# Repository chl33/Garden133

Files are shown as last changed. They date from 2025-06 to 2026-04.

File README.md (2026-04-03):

# Garden133 (v1.0.0)

Garden133 is a solar and battery-powered device for monitoring garden soil moisture levels.
It reads the moisture level of soil using a capacitive moisture sensor and transmits data via LoRa.

Please see the [Introducing Garden133](https://selectiveappeal.org/posts/garden133/) blog
post for a project overview.

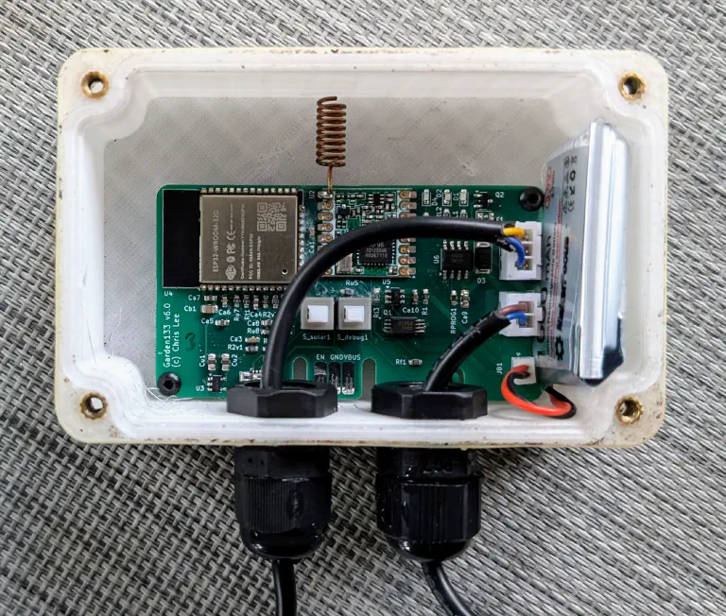
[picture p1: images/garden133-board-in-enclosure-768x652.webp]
Garden133 in enclosure


## Features
- **Modern Web Interface:** A responsive Svelte-based UI for real-time status monitoring and calibration (accessible in Debug Mode).
- **Soil Moisture Sensing:** Capacitive sensor measurement with high-precision calibration.
- **Dedicated Calibration Page:** View live ADC counts to precisely tune dry/wet thresholds.
- **Device Environmental Monitoring:** SHTC3 sensor for air temperature and humidity inside the device enclosure.
- **Power Management:** Solar charging and battery voltage monitoring.
- **LoRa Communication:** Connects to a base station ([LoRa133](https://github.com/chl33/LoRa133)) to integrate with Home Assistant.
- **OTA Updates:** Support for wireless firmware updates.

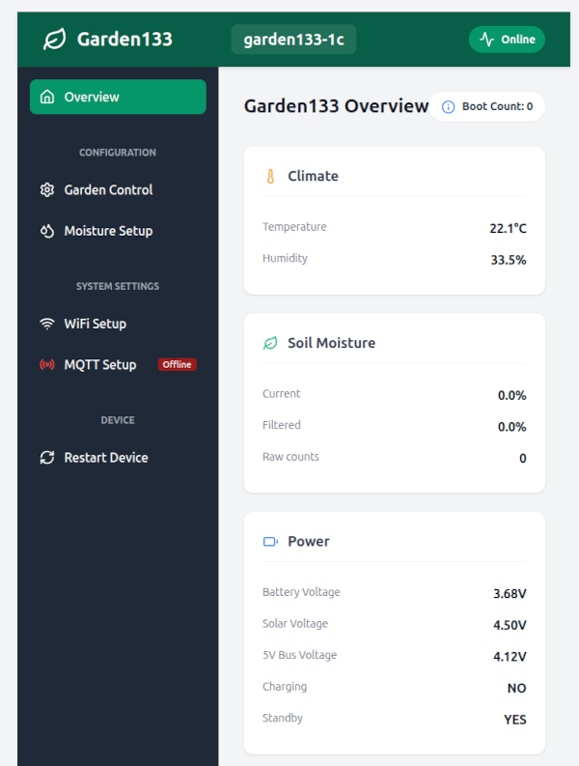
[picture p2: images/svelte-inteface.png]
Svelte Web interface


## Hardware
This project includes the custom hardware design and 3D printable parts.

- **PCB Design:** KiCAD files are available in [`KiCAD/Garden133/`](KiCAD/Garden133/).
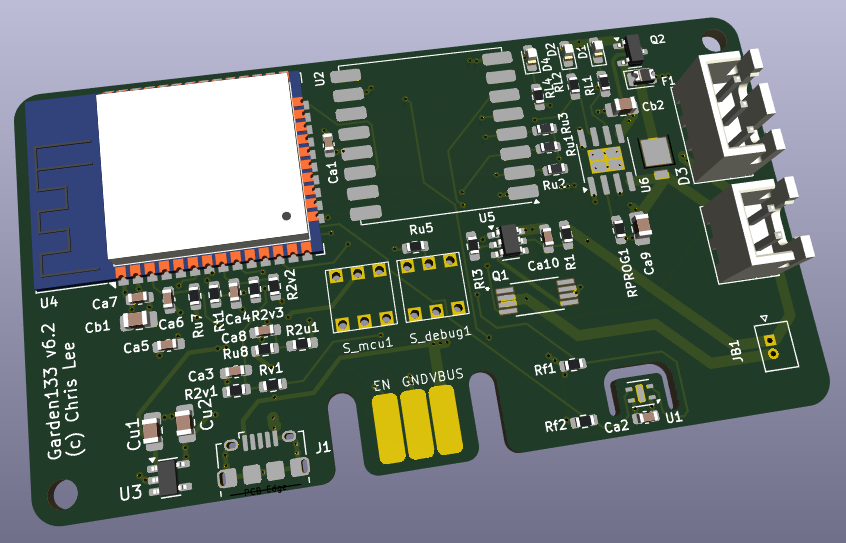
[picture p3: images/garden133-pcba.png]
Garden133 PCBA
  
- **Enclosure:** OpenSCAD files for the waterproof enclosure and mounts are in [`OpenSCAD/`](OpenSCAD/).

## Firmware Dependencies
This firmware uses the [PlatformIO](https://platformio.org/) build system and depends on the following libraries:
- [og3](https://github.com/chl33/og3): Base C++ library for ESP32/Arduino.
- [og3x-lora](https://github.com/chl33/og3x-lora): LoRa module support.
- [og3x-satellite](https://github.com/chl33/og3x-satellite): Satellite architecture support.

## Getting Started

### Prerequisites
- [PlatformIO Core](https://docs.platformio.org/en/latest/core/index.html) or VSCode with PlatformIO extension.
- An ESP32-based Garden133 board.

### Configuration
The project uses INI files for local configuration (secrets, paths, etc.) which are excluded from git.

1. **Setup Secrets:**
   Copy the example secrets file to create your local configuration:
   ```bash
   cp secrets.ini.example secrets.ini
   ```
   Edit `secrets.ini` to set your environment preferences:
   - `udpLogTarget`: IP address for UDP logging.
   - `otaPassword`: Password for Over-The-Air updates.
   - `uploadProtocol`: `esptool` (USB) or `espota` (WiFi).
   - `uploadPort`: Serial port (e.g., `/dev/ttyUSB0`) or IP address.

2. **USB vs WiFi:**
   You can also use `secrets-usb.ini.example` as a template for USB-connected development:
   ```bash
   cp secrets-usb.ini.example secrets.ini
   ```

### Building & Flashing

1. **Build the firmware:**
   ```bash
   pio run
   ```

2. **Upload the firmware:**
   ```bash
   pio run --target upload
   ```

3. **Upload Filesystem (LittleFS):**
   This uploads the `data/` directory containing web resources.
   ```bash
   pio run --target uploadfs
   ```

## License
This project is licensed under the MIT License. See `LICENSE` for details.

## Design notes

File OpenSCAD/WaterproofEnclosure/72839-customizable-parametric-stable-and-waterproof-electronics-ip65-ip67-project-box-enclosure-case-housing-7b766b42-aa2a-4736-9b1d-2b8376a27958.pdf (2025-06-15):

## Customizable parametric stable

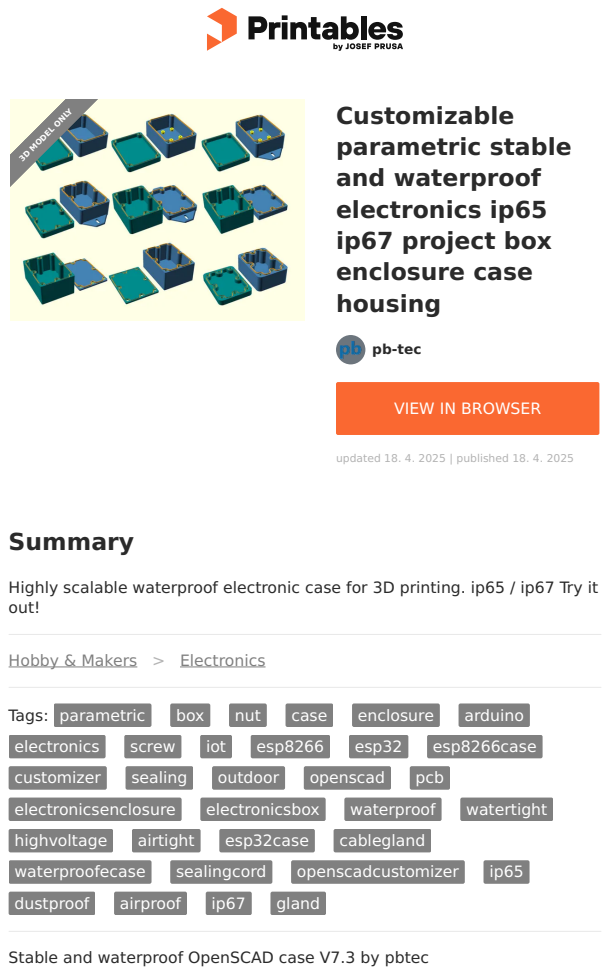
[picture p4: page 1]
Summary; Tags:; parametric; box; nut; case; enclosure; arduino; electronics; screw; iot; esp8266; esp32; esp8266case; customizer; sealing; outdoor; openscad; pcb; electronicsenclosure; electronicsbox; waterproof; watertight; highvoltage; airtight; esp32case; cablegland; waterproofecase; sealingcord; openscadcustomizer; dustproof; airproof; gland; pb-tec; and waterproof electronics ip65 ip67 project box enclosure case housing; updated 18. 4. 2025 | published 18. 4. 2025; 3D MODEL ONLY

VIEW IN BROWSER (https://printables.com/model/72839-customizable-parametric-stable-and-waterproof-elec)

Highly scalable waterproof electronic case for 3D printing. ip65 / ip67 Try it
out!

Hobby & Makers (https://printables.com/model?categoryId=48) > Electronics (https://printables.com/model?categoryId=52)

Stable and waterproof OpenSCAD case V7.3 by pbtec

Highly scalable electronic case for 3D printing. Try it out!
Optimized for Openscad Customizer. Activate it under view/customizer and play around ;-)
Openscad is free opensource software. You can download it here: https://openscad.org/

Fixed version 7.3
It seems that special characters in the code have again led to the code not working properly for some. I apologize for this. I have now created a new version 7.3 where this is fixed. I would be very interested to know if everything works as expected for you now. Thanks for your feedback in the comments

Enhancements in Version 7.2:

Hot melt copper nut support
Screw hole options: Can be configured to pass through the entire case, with the option to position the nut at the bottom of the case Flexible mounting options: 1 to 3 holes on all sides for cable glands or switches
Improved PCB support: Now compatible with up to 3 different PCBs holders instead of just one
Base bottom mounting holes added (not recommended if the housing should be highly waterproof)
Gasket can now be printed (TPU).
Expanded screw support: In addition to countersunk screws, round, flat, and hex head screws are now supported

I would love to hear whether you like the new version!

No support needed to print

You don't know Openscad? No problem. Export the stl file from Openscad (F6 then F7). Then Import the stl file into your best known 3d program to make holes for example.
You can also make the holes afterwards with the drilling machine.

Additional Screws (M2,M2.5,M3,M4 or M5), the matching nuts (hex or square) needed.
If you want to protect your electronics from humidity also “silicone sealing cord” is needed. Available at AliExpress or ebay.

For waterproof cases you can use silicone sealing cord with diameters from 1 to 3mm
To use also without sealing cord. The groove and ridge gives the housing a high stability and tightness.
Use of regular nuts or square nuts
Define outer vertical radius of corners

•
•

•

•

•

•
•

Echo output in console shows inner and outer size and more
Echo output shows the needed length of the screws
Use screws from m2 up to m5
Default are 4 screws at each corner. For large cases add addtional ones in the middle of both x and y sides if needed
Use several predefined wall mount holder, some with multiple mounting holes (up to 3)

Important!
If you use standard or square nuts, you need to pause the printer a certain level to insert the nuts
If you need a stable and waterproof case please print with 100% infill
I'm aware that sometimes, when using too big or too small parameters, there are some rendering issues. To prevent such issues change only one parameter at once and check the result.

I never tested the water proofness of this case. For more information see https://blog.prusaprinters.org/watertight-3d-printing-part-2_53638/

pbtec / pb-tec.ch
https://www.instagram.com/pbtecch/

For Projects with ESP32, ESP8266, Arduino, Raspberry, Sonoff, Shelly, IoBroker, IoT. In- and outdoor :-)

Let me see your prints, and remakes and pls don't forget to like this print

use https://paypal.me/pbtec if you want to spend me a coold beer. Thanks in advance :-)

If you want to support my project, please use the links below to start your shopping. No additional charges for you, but I get a commission of your purchases

Brass hot melting insert nuts (starter) sets: https://s.click.aliexpress.com/e/_DezuAlHhttps://s.click.aliexpress.com/e/_DeWsPMp

Or individual sizes:
https://s.click.aliexpress.com/e/_DkaQObjhttps://s.click.aliexpress.com/e/_DCrO22p

I also recommend using special hot iron to insert the nuts in the right angle:
https://s.click.aliexpress.com/e/_DcHd8Ep

round silicone sealing cord foam white
Aliexpress: https://s.click.aliexpress.com/e/_AdVXC6

## Model files

Ebay: https://www.ebay.com/itm/184394411044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 (https://www.ebay.com/itm/184394411044?siteid=0&campid=5338823684&customid=&toolid=10001)

round silicone sealing cord foam black
Aliexpress: https://s.click.aliexpress.com/e/_A32aUQ
Ebay: https://www.ebay.com/itm/353309685702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 (https://www.ebay.com/itm/353309685702?siteid=0&campid=5338823684&customid=&toolid=10001)

round silicone sealing solid cord white
Aliexpress: https://s.click.aliexpress.com/e/_A07nM2
Ebay: https://www.ebay.com/itm/133527877200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 (https://www.ebay.com/itm/133527877200?siteid=0&campid=5338823684&customid=&toolid=10001)

Some tags to better find this project:
Electrical Junction, Distribution box, Connection box, Cable Branch box,
Electronic, Housing, ip67, DIY, Project Box, Instrument Case, Wiring socket
box, Sealed, Cable gland, Shell, weatherproof, outdoor, airtight, watertight, dustproof, electronics, pcb, airproof, enclosure, parametric

sample2-ultimatewaterproofcase_v6.stl

sample1-ultimatewaterproofcase_v6.stl

ultimatewaterproofcase_v61.scad

ultimatewaterproofcase_v73.scad

## License

This work is licensed under a
Creative Commons (4.0 International License)

Attribution—Noncommercial—Share Alike (http://creativecommons.org/licenses/by-nc-sa/4.0/)

✖ | Sharing without ATTRIBUTION
✔ | Remix Culture allowed
✖ | Commercial Use
✖ | Free Cultural Works
✖ | Meets Open Definition

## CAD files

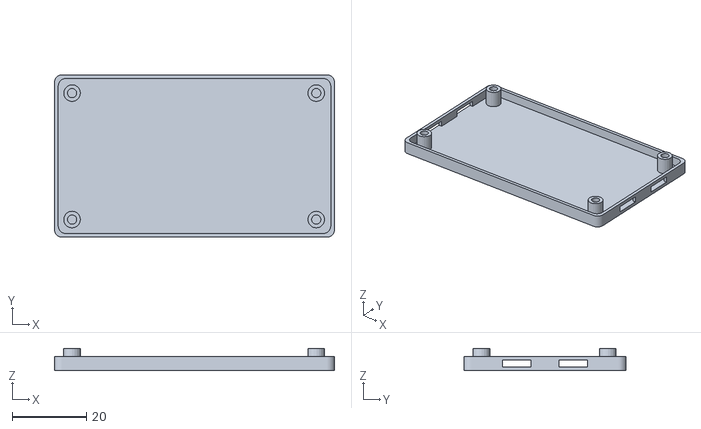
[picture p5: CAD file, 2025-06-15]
OpenSCAD/Garden133/box_bottom.stl
75.5 x 43.8 x 6.00

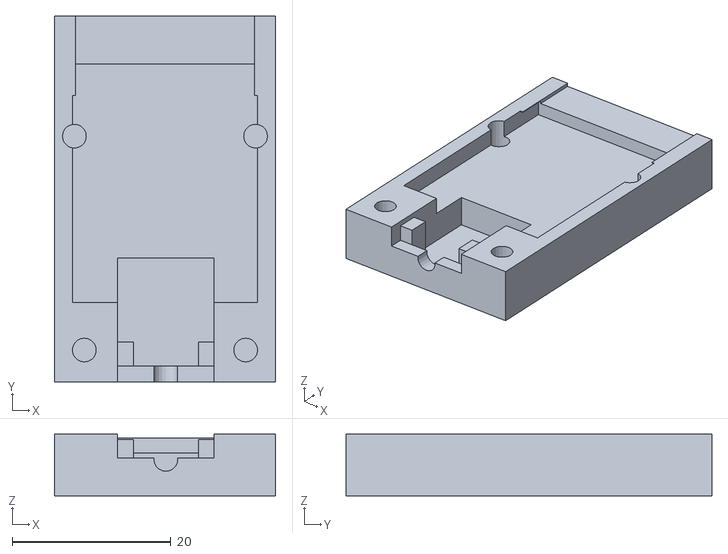
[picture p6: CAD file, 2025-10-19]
OpenSCAD/SoilMoistureCap/box_top.stl
27.8 x 46.0 x 7.78

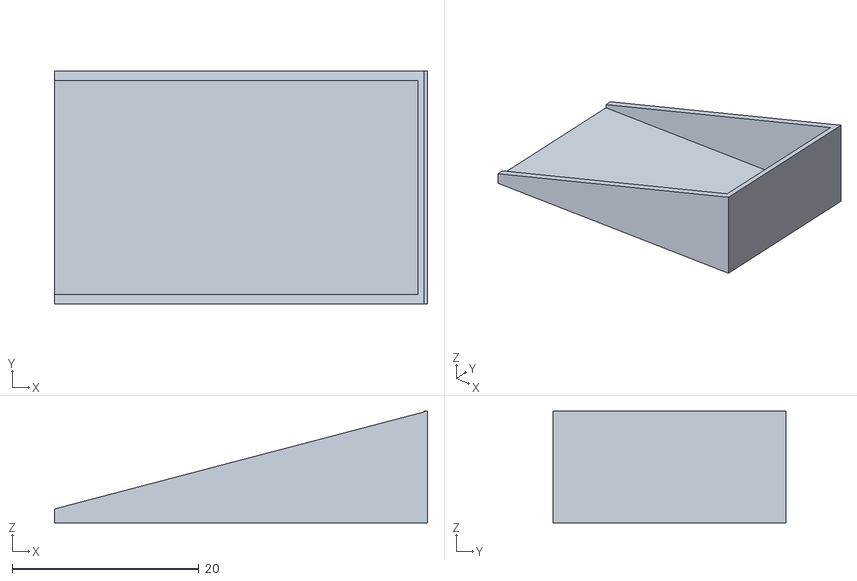
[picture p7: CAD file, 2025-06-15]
OpenSCAD/SoilPot/soilpot.stl
40.0 x 25.0 x 12.0

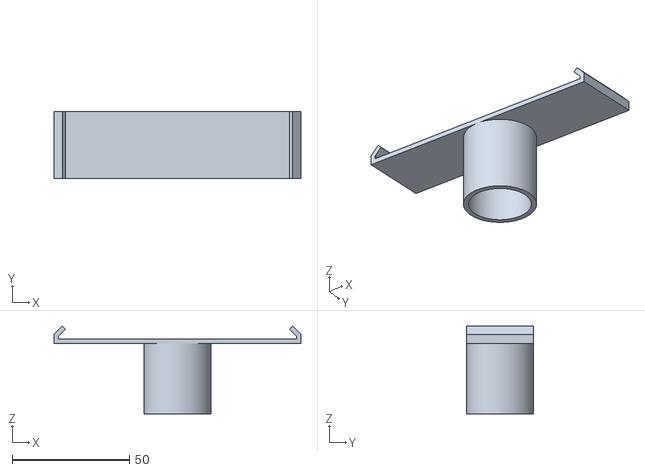
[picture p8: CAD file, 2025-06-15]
OpenSCAD/SolarPanelMount/solar_panel_mount_smaller.stl
105.5 x 28.5 x 37.5

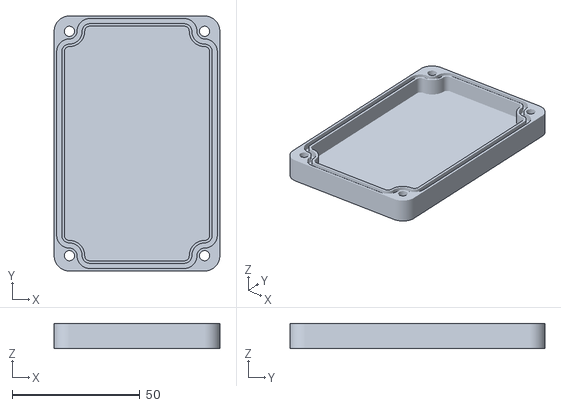
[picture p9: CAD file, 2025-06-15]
OpenSCAD/WaterproofEnclosure/garden133_case_top.stl
65.0 x 100.0 x 10.00

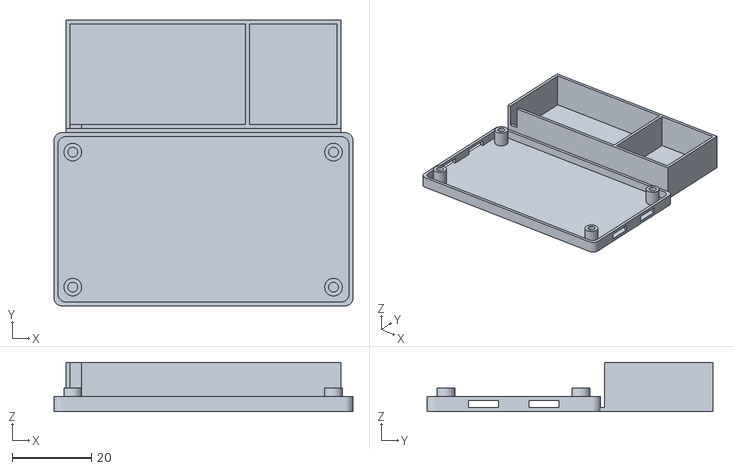
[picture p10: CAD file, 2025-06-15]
OpenSCAD/Garden133/tray.stl
75.5 x 72.2 x 12.4

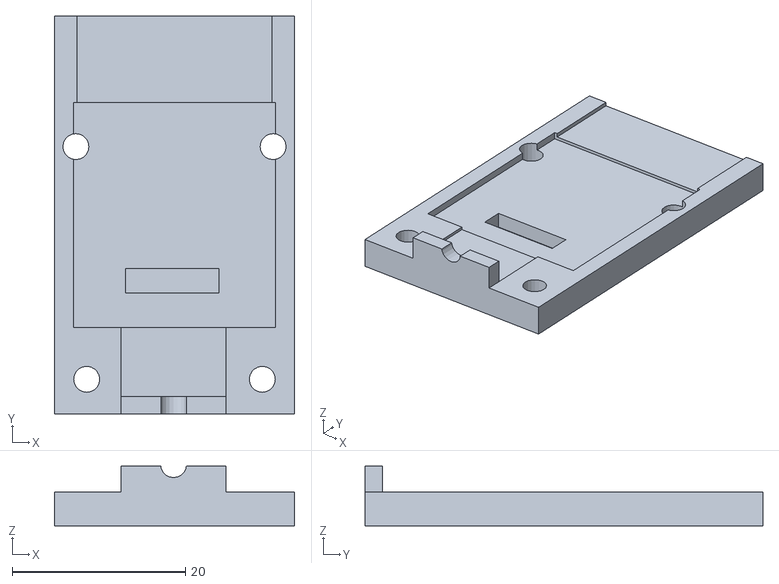
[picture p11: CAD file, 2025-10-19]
OpenSCAD/SoilMoistureCap/box_bottom.stl
27.8 x 46.0 x 6.90

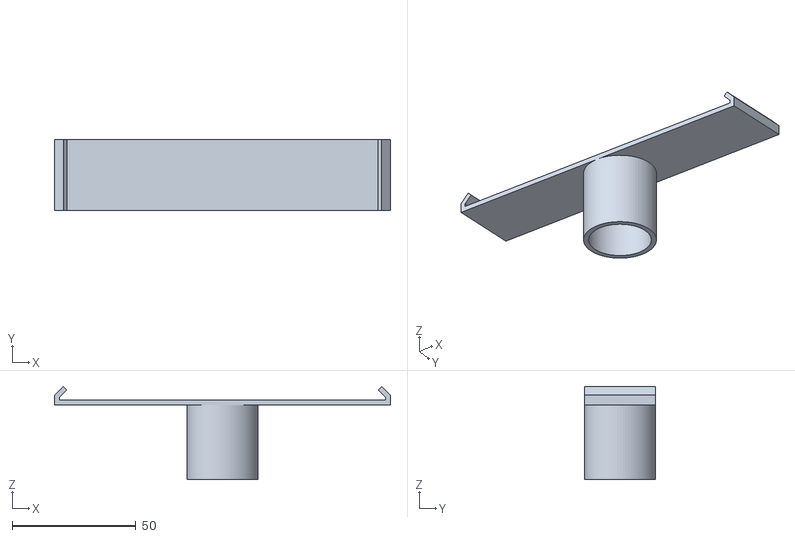
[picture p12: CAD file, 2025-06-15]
OpenSCAD/SolarPanelMount/solar_panel_mount.stl
135.5 x 28.5 x 37.5

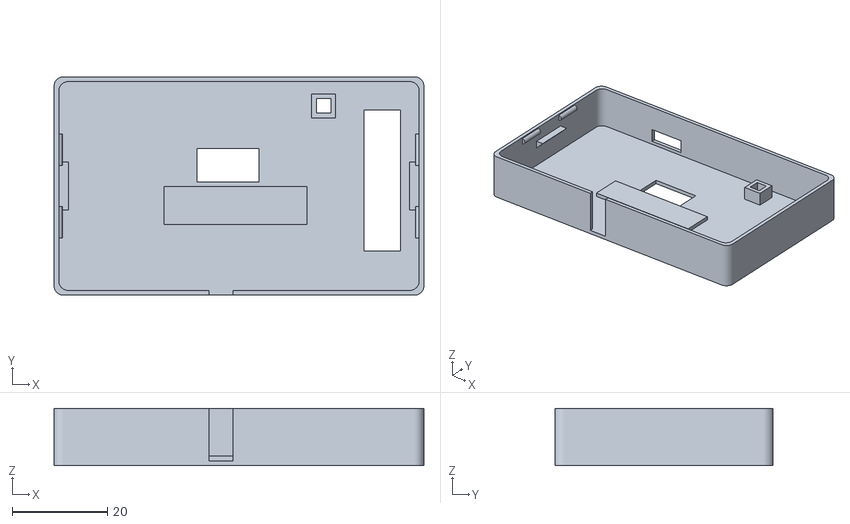
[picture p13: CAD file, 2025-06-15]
OpenSCAD/Garden133/box_top.stl
77.5 x 45.8 x 12.0

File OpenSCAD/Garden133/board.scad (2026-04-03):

// Copyright (c) 2026 Chris Lee and contributors.
// Licensed under the MIT license. See LICENSE file in the project root for details.

include <ProjectBox/project_box.scad>

board_thickness = 1.6;
pad_space = 2.54;
board_dims = [28*pad_space, 15.5*pad_space, board_thickness];

module Garden133_board() {
  u = pad_space;

  // Board imported from KiCad (VRML) -> Blender
  translate([board_dims[0]/2, board_dims[1]/2, board_dims[2]/2]) color("white")
    import(file="Garden133.stl", convexity=3);

}

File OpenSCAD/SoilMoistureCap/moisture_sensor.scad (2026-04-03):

// Copyright (c) 2026 Chris Lee and contributors.
// Licensed under the MIT license. See LICENSE file in the project root for details.

include <MCAD/units.scad>
include <ProjectBox/headers.scad>

moisture_sensor_dims = [22.5, 92, 1];

pin_offset = [6, 4, 0];
pin_size = [10, 2, 2];

cut_out_y1 = 18;
cut_out_dy1 = 1;
cut_out_dy2 = 3;
cut_out_dy = 2 * cut_out_dy1 + cut_out_dy2;
cut_out_dx = 1.75;

moisture_sensor_conn_dims = connector_nx1_dims(3);
moisture_sensor_conn_offset = 
  -header_offset
  + [moisture_sensor_dims[0] / 2,
     moisture_sensor_dims[2] - 1,
     moisture_sensor_dims[2] + moisture_sensor_conn_dims[1] / 2];


module moisture_sensor(space=false) {
  dims = moisture_sensor_dims + Z * (space ? 0.5 : 0);

  offset_val = space ? 0.5 : 0;

  msdx = moisture_sensor_dims[0];
  points = [[0, 0],      // fl
	    [0, cut_out_y1],     // l cut-out fl
	    [cut_out_dx, cut_out_y1 + cut_out_dy1],   // l cut-out fr
	    [cut_out_dx, cut_out_y1 + cut_out_dy1 + cut_out_dy2],   // l cut-out hr
	    [0, cut_out_y1 + cut_out_dy],     // l cut-out hl
	    [0, 28],     // l mid
	    [0, 85],     // hl
	    [msdx/2, moisture_sensor_dims[1]],    // point
	    [msdx, 85],    // hr
	    [msdx, 28],    // r mid
	    [msdx, cut_out_y1 + 2*cut_out_dy1 + cut_out_dy2],    // r cut-out hr
	    [msdx-cut_out_dx, cut_out_y1 + cut_out_dy1 + cut_out_dy2],  // r cut-out hl
	    [msdx-cut_out_dx, cut_out_dy],  // r cut-out fl
	    [msdx, cut_out_y1],    // r cut-out rr
	    [msdx, 0]];    // fr

  translate([1, 1, -1]*offset_val) {
    color("green") {
      linear_extrude(dims[2]+2*offset_val) {
	offset(offset_val)
	  polygon(points = points, paths = [[0, 1, 2, 3, 4, 5, 6, 7, 8, 9, 10, 11, 12, 13, 14]]);
      }
      linear_extrude(2*dims[2]+2*offset_val) {
	offset(offset_val)
	  polygon(points = points, paths = [[0, 1, 2, 3, 4, 5, 9, 10, 11, 12, 13, 14]]);
      }

      component_z = 1.5;
      translate([1, 3, dims[2]-epsilon]) cube([20, 15, component_z]);
      translate([2, 18-epsilon, dims[2]-epsilon]) cube([18, 5, component_z]);
    }
    conn_dims = moisture_sensor_conn_dims;
    if (space) {
      // Reserve simple space for connector when using difference to make space for sensor.
      gap = 0.3;
      space_dims = gap*[2,1,2] + conn_dims;
      color("white") {
	translate([(dims[0]-space_dims[0])/2, -6, dims[2]-0.6-1.4])
	  cube([space_dims[0], space_dims[2]+4.5, space_dims[1]+4]);
      }
    } else {
      translate(moisture_sensor_conn_offset) {
	rotate(180, Y) rotate(90, X) connector_nx1(3, pin_extend=false);
      }
    }
    // Location of pins on the back
    color("white")
      translate([pin_offset[0], pin_offset[1], pin_offset[2] - pin_size[2] + epsilon])
      cube(pin_size);
  }
}

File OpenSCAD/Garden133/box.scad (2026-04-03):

// Copyright (c) 2026 Chris Lee and contributors.
// Licensed under the MIT license. See LICENSE file in the project root for details.

include <ProjectBox/mounts.scad>
include <ProjectBox/project_box.scad>
include <ProjectBox/shtc3_window.scad>
include <board.scad>

ones = [1, 1, 1];

wall_thickness = 1;
gap = 0.2;
corner_radius = 2;
mount_offset = pad_space;

space_above_board = 3;
space_below_board = 5;
inner_dims = (board_dims
	      + Z*(space_above_board+space_below_board)
	      + 2*gap*ones);
outer_dims = (inner_dims
	      + 2*ones*wall_thickness
	      + [2, 2, 0] * corner_radius);

shtc3_loc = [51.8, 1.4];

buttons_loc = [30, 15];
buttons_size = [13, 7];

conn_loc = [65, 7];
conn_size  = [7.6, 29.5];

top_cutouts = [[buttons_loc, buttons_size], [conn_loc, conn_size]];

usb_cutout = [[17.75, wall_thickness+space_below_board+board_thickness-1], [9.5, 3.5]];
ym_cutouts = [usb_cutout];

// Location for "USB DBG" text to carve above buttons
text_loc = [25, 25];

antenna_cutout = [[40, -1], [5, wall_thickness+space_below_board+board_thickness+4.4]];
// antenna_cutout = [[5, wall_thickness+space_below_board+board_thickness+1], [10, 4]];
yp_cutouts = [antenna_cutout];

module in_Garden133_board_frame(board_height=false) {
  zoffset = wall_thickness + (board_height ? space_below_board : 0);
  in_board_frame(outer_dims, board_dims, zoffset) children();
}

module Garden133_box(top) {
  wall = wall_thickness;

  difference() {
    union() {
      project_box(outer_dims,
		  wall_thickness=wall_thickness,
		  gap=gap,
		  snaps_on_sides=true,
		  corner_radius=corner_radius,
		  top=top,
		  top_cutouts=top_cutouts,
		  ym_cutouts=ym_cutouts,
		  yp_cutouts=yp_cutouts);
      if (top) {
	translate([text_loc[0]-2, text_loc[1]-2, outer_dims[2]-2*wall+epsilon]) cube([30, 8, wall]);
	in_Garden133_board_frame(board_height=true)
	  shtc3_window(shtc3_loc, space_above_board+2*wall, wall, false, z_gap=1.5);
	// Bumps on top etc.
	// translate(b1o) rounded_box(b1d, corner_radius);
      } else {
	// Stuff to add on bottom.
	// Stuff to add on bottom.
	in_Garden133_board_frame() {
	  at_corners(board_dims+1.0*X, mount_offset, x_extra=-1.2, y_extra=-0.2)
	    screw_mount(space_below_board, wall, 2.5/2);
	}
	
      }	
    }
    // Cut outs.
    if (top) {
      in_Garden133_board_frame(board_height=true)
	shtc3_window(shtc3_loc, space_above_board+wall+1, wall, true, z_gap=1);
      
      // Negative space of bumps.
      // translate(b1o+[wall, wall, -epsilon]) rounded_box(b1d-wall*[2, 2, 1], corner_radius);
      // translate(b2o+[wall, wall, -epsilon]) rounded_box(b2d-wall*[2, 2, 1], corner_radius);

      translate([text_loc[0], text_loc[1], outer_dims[2]-0.5+epsilon])
	linear_extrude(0.5) text("USB DBG", size=4);
    }
  }
}

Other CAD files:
OpenSCAD/Garden133/box_bottom.scad
OpenSCAD/Garden133/Garden133_test.scad
OpenSCAD/Garden133/box_top.scad
OpenSCAD/Garden133/gui.scad
OpenSCAD/Garden133/tray.scad
OpenSCAD/SoilMoistureCap/box_bottom.scad
OpenSCAD/SoilMoistureCap/box_top.scad
OpenSCAD/SoilMoistureCap/cap2.scad
OpenSCAD/SoilMoistureCap/sensor_test.scad
OpenSCAD/SoilMoistureCap/test_cap.scad
OpenSCAD/SoilPot/soilpot.scad
OpenSCAD/SolarPanelMount/solar_panel_mount.scad
OpenSCAD/WaterproofEnclosure/ultimatewaterproofcase_v73.scad

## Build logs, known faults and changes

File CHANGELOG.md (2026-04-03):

# Changelog

All notable changes to this project will be documented in this file.

The format is based on [Keep a Changelog](https://keepachangelog.com/en/1.0.0/),
and this project adheres to [Semantic Versioning](https://semver.org/spec/v2.0.0.html).

## [1.0.0] - 2026-03-29

### Added
- New responsive Svelte web interface for status monitoring and configuration (Debug Mode).
- JSON API for full device control and status reporting.
- Standardized `camelCase` naming for all API keys and internal variables.
- Dedicated Moisture Calibration page with live ADC count monitoring.
- Explicit support for Frequency, Spreading Factor, and Signal Bandwidth configuration via Web UI.
- Support for larger partition tables (`min_spiffs.csv`) to accommodate web assets and restore OTA functionality.

### Changed
- Improved moisture sensor calibration accuracy and reliability.
- Reorganized web server routes (legacy HTML interface moved to `/old`).
- Standardized variable naming across firmware and frontend.

### Fixed
- Fixed bug where moisture sensor configuration was not being correctly registered/saved.
- Resolved `undefined` property errors in the web UI for sensor readings.
- Fixed empty dropdowns for LoRa parameters on page reload.
- Corrected ADC voltage sensor naming to match project standards.

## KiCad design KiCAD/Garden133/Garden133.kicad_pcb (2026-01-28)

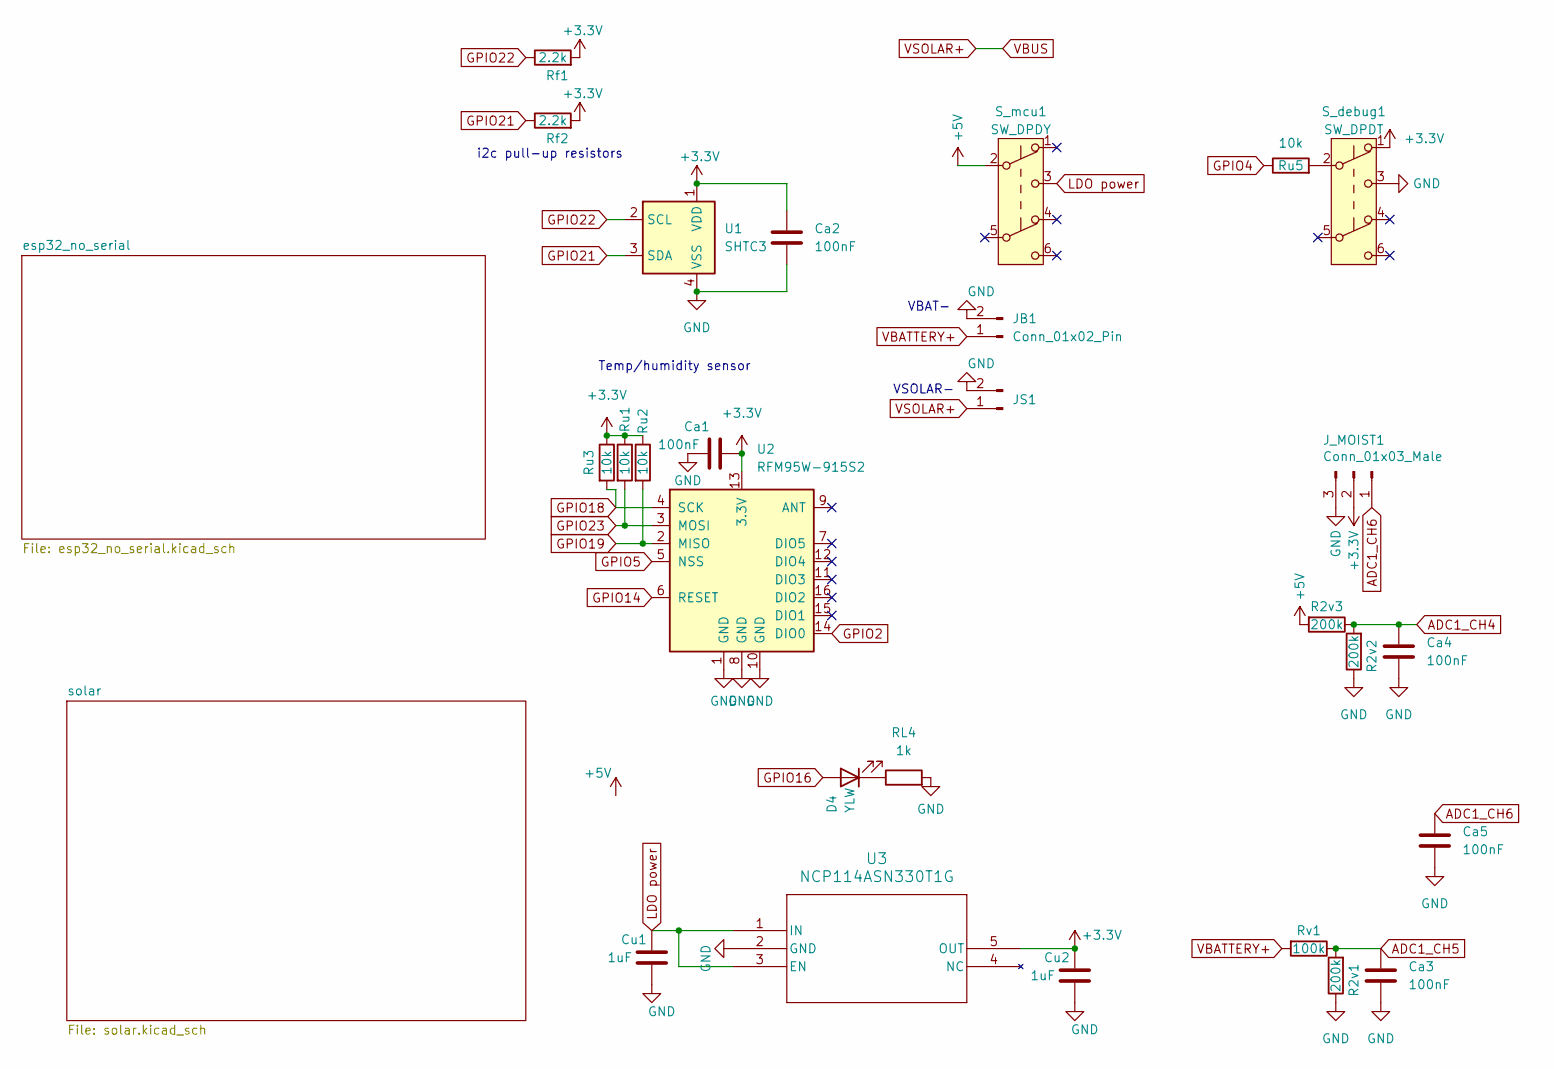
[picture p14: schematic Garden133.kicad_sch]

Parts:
Ca1, Ca2: 100nF; C_0603_1608Metric
Ca3, Ca4, Ca5: 100nF; C_0603_1608Metric_Pad1.08x0.95mm_HandSolder
Cu1, Cu2: 1uF; C_0805_2012Metric_Pad1.18x1.45mm_HandSolder
D4: YLW; LED_0603_1608Metric_Pad1.05x0.95mm_HandSolder
JB1: Conn_01x02_Pin; MOLEX_530470210
JS1: Conn_01x02_Pin; JST_XH_B2B-XH-A_1x02_P2.50mm_Vertical
J_MOIST1: Conn_01x03_Male; JST_XH_B3B-XH-A_1x03_P2.50mm_Vertical
R2v1, R2v2, R2v3: 200k; R_0603_1608Metric
RL4: 1k; R_0603_1608Metric_Pad0.98x0.95mm_HandSolder
Rf1, Rf2: 2.2k; R_0603_1608Metric
Ru1, Ru2, Ru3, Ru5: 10k; R_0603_1608Metric
Rv1: 100k; R_0603_1608Metric
S_debug1: SW_DPDT; SW_SPDT_5.8x5.8_locking
S_mcu1: SW_DPDY; SW_SPDT_5.8x5.8_locking
U1: SHTC3; Sensirion_DFN-4-1EP_2x2mm_P1mm_EP0.7x1.6mm
U2: RFM95W-915S2; HOPERF_RFM9XW_SMD
U3: NCP114ASN330T1G; TSOT-23-5

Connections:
+3.3V: Ca1.2, Ca2.1, Cu2.1, J_MOIST1.2, Rf1.2, Rf2.2, Ru1.1, Ru2.1, Ru3.1, S_debug1.1 (A), U1.1 (VDD), U2.13 (3.3V), U3.5 (OUT); also elsewhere on the board
+5V: R2v3.2, S_mcu1.2 (B); also elsewhere on the board
ADC1_CH4: Ca4.2, R2v2.2, R2v3.1; also elsewhere on the board
ADC1_CH5: Ca3.2, R2v1.2, Rv1.1; also elsewhere on the board
ADC1_CH6: Ca5.2, J_MOIST1.1; also elsewhere on the board
GND: Ca1.1, Ca2.2, Ca3.1, Ca4.1, Ca5.1, Cu1.2, Cu2.2, JB1.2, JS1.2, J_MOIST1.3, R2v1.1, R2v2.1, RL4.2, S_debug1.3 (C), U1.4 (VSS), U2.1 (GND), U2.8 (GND), U2.10 (GND), U3.2 (GND); also elsewhere on the board
GPIO2: U2.14 (DIO0); also elsewhere on the board
GPIO4: Ru5.1; also elsewhere on the board
GPIO5: U2.5 (NSS); also elsewhere on the board
GPIO14: U2.6 (RESET); also elsewhere on the board
GPIO16: D4.2 (A); also elsewhere on the board
GPIO18: Ru3.2, U2.4 (SCK); also elsewhere on the board
GPIO19: Ru2.2, U2.2 (MISO); also elsewhere on the board
GPIO21: Rf2.1, U1.3 (SDA); also elsewhere on the board
GPIO22: Rf1.1, U1.2 (SCL); also elsewhere on the board
GPIO23: Ru1.2, U2.3 (MOSI); also elsewhere on the board
LDO power: Cu1.1, S_mcu1.3 (C), U3.1 (IN), U3.3 (EN)
unnamed: D4.1 (K), RL4.1
unnamed: Ru5.2, S_debug1.2 (B)
VBATTERY+: JB1.1, Rv1.2; also elsewhere on the board
VBUS: JS1.1; also elsewhere on the board

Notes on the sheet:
VSOLAR-
Temp/humidity sensor
i2c pull-up resistors
VBAT-

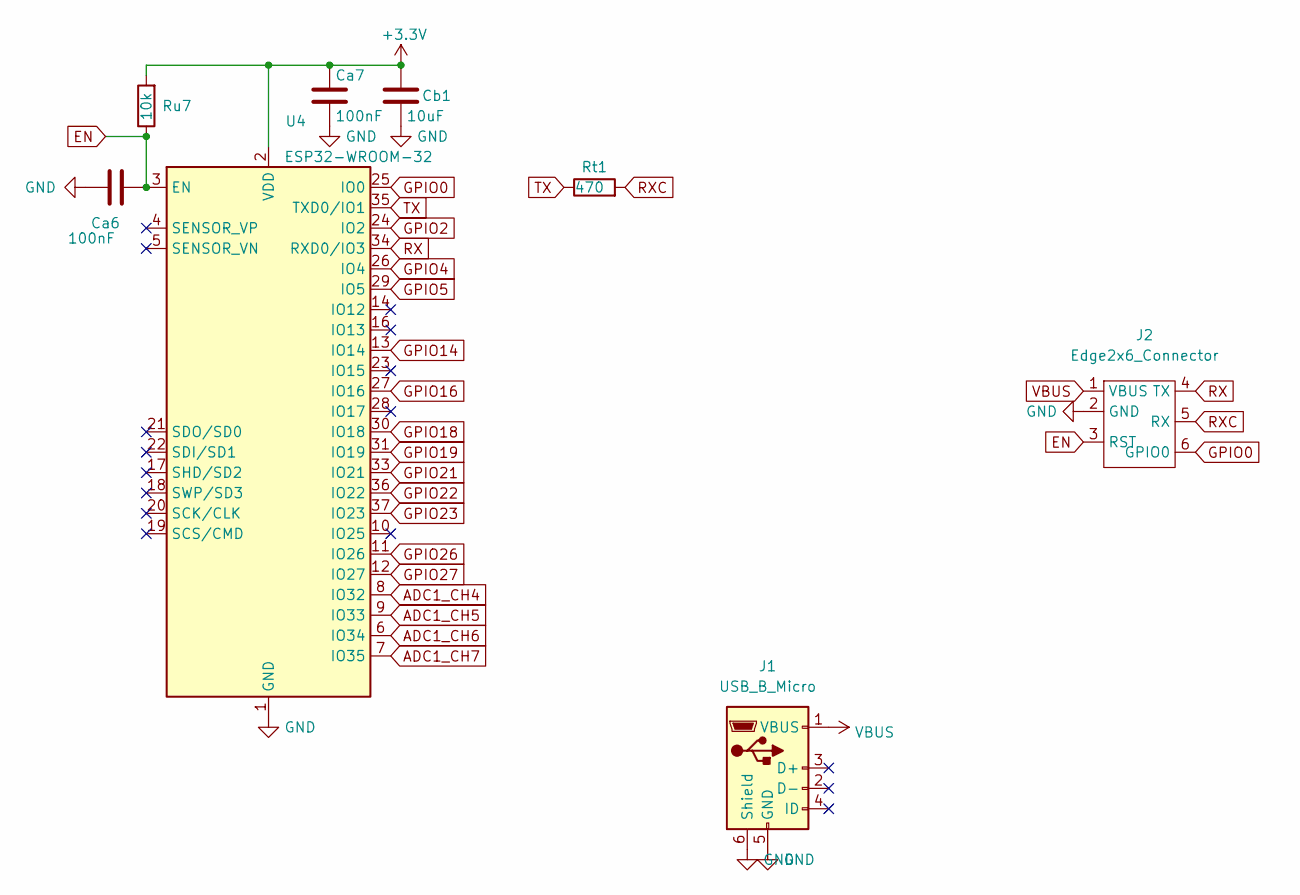
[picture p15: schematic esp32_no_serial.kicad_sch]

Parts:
Ca6, Ca7: 100nF; C_0603_1608Metric
Cb1: 10uF; C_0805_2012Metric_Pad1.18x1.45mm_HandSolder
J1: USB_B_Micro; USB_Micro-B_Amphenol_10118194_Horizontal
J2: Edge2x6_Connector; EdgeConnector_2x3
Rt1: 470; R_0603_1608Metric
Ru7: 10k; R_0603_1608Metric
U4: ESP32-WROOM-32

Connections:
+3.3V: Ca7.1, Cb1.1, Ru7.2, U4.2 (VDD); also elsewhere on the board
ADC1_CH4: U4.8 (IO32); also elsewhere on the board
ADC1_CH5: U4.9 (IO33); also elsewhere on the board
ADC1_CH6: U4.6 (IO34); also elsewhere on the board
ADC1_CH7: U4.7 (IO35); also elsewhere on the board
EN: Ca6.2, J2.3 (RST), Ru7.1, U4.3 (EN)
GND: Ca6.1, Ca7.2, Cb1.2, J1.5 (GND), J1.6 (Shield), J2.2 (GND), U4.1 (GND), U4.15 (GND), U4.38 (GND), U4.39 (GND); also elsewhere on the board
GPIO0: J2.6 (GPIO0), U4.25 (IO0)
GPIO2: U4.24 (IO2); also elsewhere on the board
GPIO4: U4.26 (IO4); also elsewhere on the board
GPIO5: U4.29 (IO5); also elsewhere on the board
GPIO14: U4.13 (IO14); also elsewhere on the board
GPIO16: U4.27 (IO16); also elsewhere on the board
GPIO18: U4.30 (IO18); also elsewhere on the board
GPIO19: U4.31 (IO19); also elsewhere on the board
GPIO21: U4.33 (IO21); also elsewhere on the board
GPIO22: U4.36 (IO22); also elsewhere on the board
GPIO23: U4.37 (IO23); also elsewhere on the board
GPIO26: U4.11 (IO26); also elsewhere on the board
GPIO27: U4.12 (IO27); also elsewhere on the board
RX: J2.4 (TX), U4.34 (RXD0/IO3)
RXC: J2.5 (RX), Rt1.2
TX: Rt1.1, U4.35 (TXD0/IO1)
VBUS: J1.1 (VBUS), J2.1 (VBUS); also elsewhere on the board

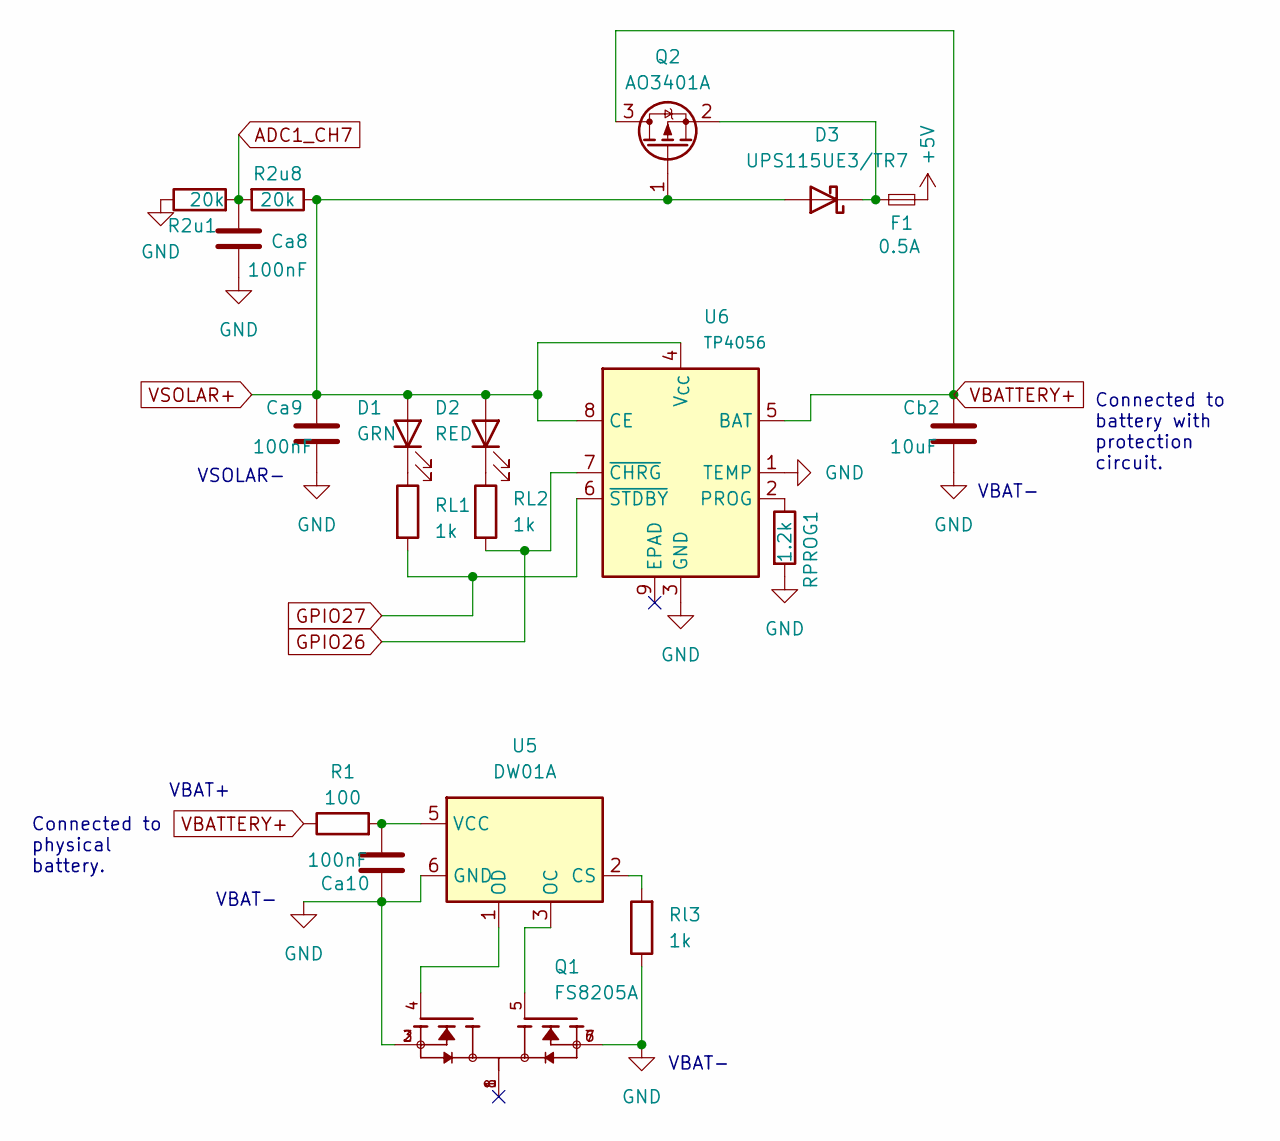
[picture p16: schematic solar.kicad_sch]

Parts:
Ca8, Ca10: 100nF; C_0603_1608Metric_Pad1.08x0.95mm_HandSolder
Ca9: 100nF; C_0805_2012Metric_Pad1.18x1.45mm_HandSolder
Cb2: 10uF; C_0805_2012Metric_Pad1.18x1.45mm_HandSolder
D1: GRN; LED_0603_1608Metric_Pad1.05x0.95mm_HandSolder
D2: RED; LED_0603_1608Metric_Pad1.05x0.95mm_HandSolder
D3: UPS115UE3/TR7; DO-216
F1: 0.5A; D_0805_2012Metric
Q1: FS8205A; SOP65P640X120-8N; PARTREV 1.7
Q2: AO3401A; SOT-23
R1: 100; R_0603_1608Metric_Pad0.98x0.95mm_HandSolder
R2u1: 20k; R_0603_1608Metric_Pad0.98x0.95mm_HandSolder
R2u8: 20k; R_0603_1608Metric
RL1, RL2: 1k; R_0603_1608Metric_Pad0.98x0.95mm_HandSolder
RPROG1: 1.2k; R_0603_1608Metric_Pad0.98x0.95mm_HandSolder
Rl3: 1k; R_0603_1608Metric_Pad0.98x0.95mm_HandSolder
U5: DW01A; SOT-23-6; LCSC C61503
U6: TP4056; SOIC-8-1EP_3.9x4.9mm_P1.27mm_EP2.41x3.3mm_ThermalVias

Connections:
+5V: F1.2; also elsewhere on the board
ADC1_CH7: Ca8.2, R2u1.2, R2u8.2; also elsewhere on the board
GND: Ca8.1, Ca9.2, Ca10.2, Cb2.2, Q1.2, Q1.3, Q1.6, Q1.7, R2u1.1, RPROG1.2, Rl3.1, U5.6 (GND), U6.1 (TEMP), U6.3 (GND); also elsewhere on the board
GPIO26: RL2.2, U6.7 (~CHRG); also elsewhere on the board
GPIO27: RL1.2, U6.6 (~STDBY); also elsewhere on the board
unnamed: D1.1 (K), RL1.1
unnamed: D2.1 (K), RL2.1
unnamed: D3.1 (K), F1.1, Q2.2 (S)
unnamed: Rl3.2, U5.2 (CS)
unnamed: Q1.5, U5.3 (OC)
unnamed: Q1.4, U5.1 (OD)
unnamed: Ca10.1, R1.2, U5.5 (VCC)
unnamed: RPROG1.1, U6.2 (PROG)
VBATTERY+: Cb2.1, Q2.3 (D), R1.1, U6.5 (BAT); also elsewhere on the board
VBUS: Ca9.1, D1.2 (A), D2.2 (A), D3.2 (A), Q2.1 (G), R2u8.1, U6.4 (V_{CC}), U6.8 (CE); also elsewhere on the board

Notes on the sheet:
VBAT-
Connected to battery with protection circuit.
VBAT+
Connected to physical battery.
VSOLAR-

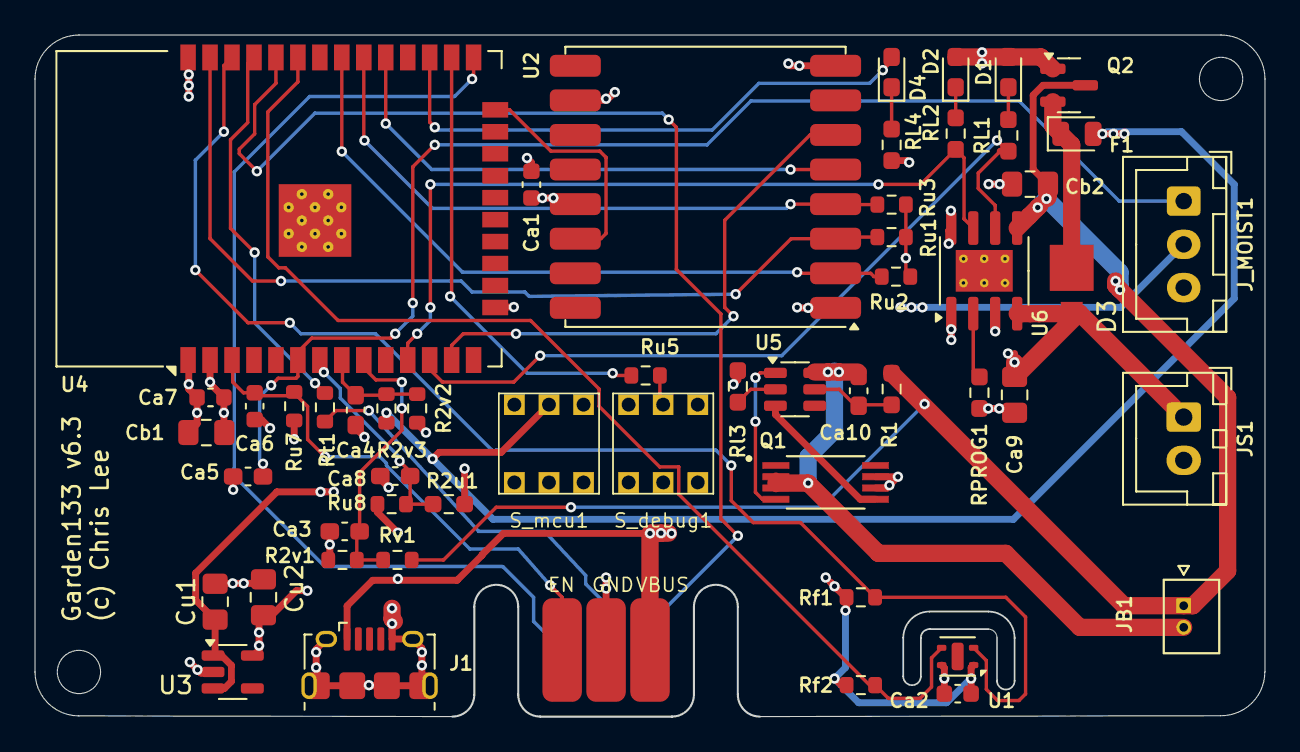
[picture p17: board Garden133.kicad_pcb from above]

Board: 4 copper layers, 71.1 x 39.4 mm, 54 parts (0 on the bottom side), 37 nets.

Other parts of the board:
Ru8: 20k; R_0603_1608Metric

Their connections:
ADC1_CH7: Ru8.2; also elsewhere on the board
VBUS: Ru8.1; also elsewhere on the board

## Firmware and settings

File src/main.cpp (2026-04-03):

// Copyright (c) 2026 Chris Lee and contributors.
// Licensed under the MIT license. See LICENSE file in the project root for details.

#include <Arduino.h>
#include <LittleFS.h>
#include <og3/adc_voltage.h>
#include <og3/blink_led.h>
#include <og3/config_module.h>
#include <og3/constants.h>
#include <og3/din.h>
#include <og3/ha_app.h>
#include <og3/html_table.h>
#include <og3/kernel_filter.h>
#include <og3/lora.h>
#include <og3/mapped_analog_sensor.h>
#include <og3/packet_writer.h>
#include <og3/satellite.h>
#include <og3/shtc3.h>
#include <og3/tasks.h>
#include <og3/units.h>
#include <og3/web_server.h>
#include <pb_encode.h>

#include <memory>
#include <vector>

#include "svelteesp32async.h"

#define VERSION_MAJOR 1
#define VERSION_MINOR 0
#define VERSION_PATCH 0
#define STR(X) #X
#define MAKE_VERSION(MAJOR, MINOR, PATCH) STR(MAJOR) "." STR(MINOR) "." STR(PATCH)
#define VERSION MAKE_VERSION(VERSION_MAJOR, VERSION_MINOR, VERSION_PATCH)

#if HARDWARE_VERSION_MAJOR > 5
#define HAVE_STANDBY_INPUT
#endif

// TODO
// - Use interrupt on tx-finished to sleep (didn't work so far).
// - LoRa.setTxPower(int level); (??)

namespace og3 {

static const char kManufacturer[] = "Chris Lee";
static const char kModel[] = "Garden133";
static const char kSoftware[] = "Garden133 v" VERSION;

constexpr App::LogType kLogType = LOG_METHOD;
constexpr uint32_t kCleeOrg = 0xc133;
constexpr uint16_t kDevicePktType = 0xde1c;

constexpr size_t kLoraPacketSize = 255;

uint16_t s_board_id = 0xFF;

HAApp s_app(
    HAApp::Options(kManufacturer, kModel,
                   WifiApp::Options()
                       .withSoftwareName(kSoftware)
                       .withDefaultDeviceName(kModel)
#if defined(LOG_UDP) && defined(LOG_UDP_ADDRESS)
                       .withUdpLogHost(IPAddress(LOG_UDP_ADDRESS))

#endif
                       .withOta(OtaManager::Options(OTA_PASSWORD))
                       .withApp(App::Options().withLogType(kLogType).withReserveTasks(64))));

VariableGroup s_vg("garden");
VariableGroup s_cvg("garden_config");

static const char kTemperature[] = "temperature";
static const char kHumidity[] = "humidity";

// Hardware config
// Define the pins used by the transceiver module.
constexpr int kLoraSS = 5;
constexpr int kLoraRst = 14;
constexpr int kLoraDio0 = 2;

constexpr int kFiveVPin = 32;      // ADC1_CH4
constexpr int kBatteryPin = 33;    // ADC1_CH5
constexpr int kMoisturePin = 34;   // ADC1_CH6
constexpr int kSolarPlusPin = 35;  // ADC1_CH7
constexpr int kDebugSwitchPin = 04;
constexpr int kLedPin = 16;
#if defined(HAVE_STANDBY_INPUT)
// NOTE: it looks from the circuit diagram that these pins should be reversed, but
//  these are the pin assignments that work in testing.
constexpr int kChrgPin = 27;
constexpr int kStbyPin = 26;
#endif

// Default sleep for 5 minute between readings (for now).
constexpr unsigned kDefaultSleepMin = 5;

// Number of samples to store for the moisture filter.
constexpr unsigned kFilterSize = 32;

namespace Status {
constexpr unsigned kDebugMode = 0x1;
constexpr unsigned kPowerOn = 0x2;
constexpr unsigned kDeepSleep = 0x4;
constexpr unsigned kFilterRestoreFailure = 0x8;
constexpr unsigned kFilterSaveFailure = 0x10;
}  // namespace Status

constexpr unsigned kBlinkMsec = 100;

// This data should persist during deep sleep.
// DO NOT SET INITIALIZERS ON THESE VALUES!
RTC_DATA_ATTR struct {
  unsigned bootCount;
  byte mac[6];
  KernelFilter::State<kFilterSize> filter_state;
  unsigned code;
  satellite::PacketSender::Rtc packet_sender;
  unsigned last_wake_secs;
  unsigned expected_wake_secs;
} s_rtc;

bool s_boot = false;
bool s_lora_ok = false;
bool s_is_debug_mode = false;

BlinkLed s_led("mode_led", kLedPin, &s_app, kBlinkMsec, false);

Shtc3 s_shtc3(kTemperature, kHumidity, &s_app.module_system(), "temperature", s_vg);

// To get to 1% radio utilization, should transmit every 4 minutes maximum.
// Assuming a 86 byte packet.
// 86 bytes / (288 bits/s / 8 bits/byte) = 2.4 seconds to transmit
// So cannot transmit more often than everty (100 * 2.4 seconds) / (60 sec / min) = 4 minutes

auto s_lora_options = []() -> LoRaModule::Options {
  LoRaModule::Options opts;
  opts.sync_word = 0xF0;
  opts.enable_crc = true;
  // opts.on_transmit_done = []() { s_led.off(); };

  opts.frequency = lora::Frequency::k915MHz;
  opts.spreading_factor = lora::SpreadingFactor::kSF8;
  opts.signal_bandwidth = lora::SignalBandwidth::k125kHz;

  const auto opt_select = static_cast<LoRaModule::OptionSelect>(LoRaModule::kOptionSyncWord |
                                                                LoRaModule::kOptionSpreadingFactor |
                                                                LoRaModule::kOptionSignalBandwidth);
  opts.config_options = opt_select;
  opts.settable_options = opt_select;

  return opts;
};

VariableGroup s_lora_vg("lora");
LoRaModule s_lora(s_lora_options(), &s_app, s_lora_vg, nullptr);

Variable<unsigned> s_sleep_min("sleepMin", kDefaultSleepMin, units::kMinutes, "sleep min",
                               VariableBase::kSettable | VariableBase::kConfig, s_lora_vg);

template <typename T>
void copy(T& dest, const T& src) {
  memcpy(&dest, &src, sizeof(dest));
}

void add_html_button(String* body, const char* title, const char* url) {
  *body += F("<p><form action='");
  *body += url;
  *body += F("' method='get'><button>");
  *body += title;
  *body += F("</button></form></p>\n");
}

// Global variable for html, so asyncwebserver can send data in the background (single client)
String s_html;

class MoistureSensor : public ConfigModule {
 public:
  MoistureSensor()
      : ConfigModule("moisture", &s_app),
        m_mapped_adc(
            {
                .name = "moisture",
                .pin = kMoisturePin,
                .units = units::kPercentage,
                .raw_description = "soil moisture raw value",
                .description = "soil moisture",
                .raw_var_flags = 0,
                .mapped_var_flags = 0,
                .config_flags = kCfgSet,
                .default_in_min = kNoMoistureCounts,
                .default_in_max = kFullMoistureCounts,
                .default_out_min = 0.0f,
                .default_out_max = 100.0f,
                .config_decimals = 0,
                .decimals = 1,
                .valid_in_min = 50,
                .valid_in_max = 1 << 12,
            },
            &s_app.module_system(), m_cvg, s_vg) {}
  float read() { return m_mapped_adc.read(); }
  float value() const { return m_mapped_adc.value(); }
  int raw_counts() const { return m_mapped_adc.raw_counts(); }
  Variable<unsigned>& countsVar() { return m_mapped_adc.raw_value(); }
  VariableGroup& configVarGroup() { return m_cvg; }

 private:
  // Multiple constants by 2/3 compared to Plant133 due to voltage divider.
  // Default ADC reading at which to consider soil moisture to be 100%.
  static constexpr unsigned kFullMoistureCounts = 355;  // 2*1000/3;
  // Default ADC reading at which to consider soil moisture to be 0%.
  static constexpr unsigned kNoMoistureCounts = 780;  // 2*2800/2;

  static constexpr unsigned kCfgSet = VariableBase::Flags::kConfig | VariableBase::Flags::kSettable;

  MappedAnalogSensor m_mapped_adc;
};

constexpr float kSoilSensorSigmaSecs = 30 * kSecInMin;

MoistureSensor s_moisture;
KernelFilter s_moisture_filter(
    {
        .name = "soil moisture",
        .units = units::kPercentage,
        .description = nullptr,
        .var_flags = 0,
        .sigma = kSoilSensorSigmaSecs,
        .decimals = 1,
        .size = kFilterSize,
    },
    &s_app.module_system(), s_vg);

int64_t total_usecs() {
  const int64_t wake_sleep_usecs = static_cast<int64_t>(s_rtc.expected_wake_secs) * kUsecInSec;
  return esp_timer_get_time() + wake_sleep_usecs;
}

AdcVoltage s_five_v_sensor("fivevVoltage", &s_app, kFiveVPin, "fivev raw value",
                           "voltage from battery or solar", 3.3 * 2, s_vg, s_cvg);

AdcVoltage s_battery_sensor("batteryVoltage", &s_app, kBatteryPin, "battery raw value", nullptr,
                            3.3 * 32.0 / 22.0, s_vg, s_cvg);

AdcVoltage s_solar_sensor("solarVoltage", &s_app, kSolarPlusPin, "solar raw value", nullptr,
                          3.3 * 2, s_vg, s_cvg);

Variable<unsigned> s_status_var("status", 0, nullptr, "status flags", 0, s_vg);
Variable<unsigned> s_board_id_var("board id", 0, nullptr, nullptr, 0, s_vg);
Variable<unsigned> s_wake_secs("wake_secs", s_rtc.expected_wake_secs, units::kSeconds, nullptr, 0,
                               s_vg);
Variable<unsigned> s_last_wake_secs("last_wake_secs", s_rtc.last_wake_secs, units::kSeconds,
                                    nullptr, 0, s_vg);
#if defined(HAVE_STANDBY_INPUT)
constexpr bool kDinPublish = true;
constexpr bool kDinInvert = false;
DIn s_din_chrg("chrg", &s_app.module_system(), kChrgPin, nullptr, s_vg, kDinPublish, kDinInvert);
DIn s_din_stby("stby", &s_app.module_system(), kStbyPin, nullptr, s_vg, kDinPublish, kDinInvert);
Variable<unsigned> s_var_charge("charge", 0, nullptr, nullptr, VariableBase::Flags::kNoPublish,
                                s_vg);
Variable<unsigned> s_var_standby("standby", 0, nullptr, nullptr, VariableBase::Flags::kNoPublish,
                                 s_vg);
#endif

#define SETSTR(X, VAL) strncpy(X, (VAL), sizeof(X) - 1)

class PacketTemperatureReading : public satellite::PacketFloatReading {
 public:
  PacketTemperatureReading(unsigned sensor_id, Shtc3& shtc3)
      : PacketFloatReading(sensor_id, og3_Sensor_Type_TYPE_TEMPERATURE, shtc3.temperatureVar()),
        m_shtc3(shtc3) {}

  bool read() final {
    m_shtc3.read();
    return m_shtc3.ok();
  }
  bool write(og3_Packet& packet) final { return PacketFloatReading::write(packet); }

 private:
  Shtc3& m_shtc3;
};

class PacketHumidityReading : public satellite::PacketFloatReading {
 public:
  PacketHumidityReading(unsigned sensor_id, Shtc3& shtc3)
      : PacketFloatReading(sensor_id, og3_Sensor_Type_TYPE_HUMIDITY, shtc3.humidityVar()),
        m_shtc3(shtc3) {}

  bool read() final {
    // Assume read() happened in PacketTemperatureReading
    return m_shtc3.ok();
  }
  bool write(og3_Packet& packet) final {
    if (!m_shtc3.ok()) {
      return false;
    }
    return PacketFloatReading::write(packet);
  }

 private:
  Shtc3& m_shtc3;
};

class PacketMoistureReading : public satellite::PacketFloatReading {
 public:
  static constexpr float kMinVForValidReading = 3.2f;

  PacketMoistureReading(unsigned sensor_id, MoistureSensor& moisture, KernelFilter& moisture_filter)
      : PacketFloatReading(sensor_id, og3_Sensor_Type_TYPE_MOISTURE,
                           moisture_filter.valueVariable(),
                           og3_Sensor_StateClass_STATE_CLASS_MEASUREMENT),
        m_moisture(moisture),
        m_moisture_filter(moisture_filter) {}

  bool read() {
    // When the power supply is < 3.2V, it seems moisture sensor readings are not trustworthy.
    m_is_ok = s_five_v_sensor.read() > kMinVForValidReading;
    if (!m_is_ok) {
      return false;
    }
    const int64_t now_usecs = total_usecs();
    m_moisture_filter.addSample(now_usecs * 1e-6, m_moisture.read());
    return true;
  }
  bool write(og3_Packet& packet) final {
    if (!m_is_ok) {
      return false;
    }
    return PacketFloatReading::write(packet);
  }

 private:
  MoistureSensor& m_moisture;
  KernelFilter& m_moisture_filter;
  bool m_is_ok = false;
};

class LoraPacketSender : public satellite::PacketSender {
 public:
  LoraPacketSender(og3_Device* device, og3::App* app, og3::satellite::PacketSender::Rtc* rtc)
      : satellite::PacketSender(device, app, rtc), m_mutable_device(device) {
    auto idx = [this]() { return m_readings.size(); };
    m_readings.reserve(10);
    m_readings.emplace_back(new PacketTemperatureReading(idx(), s_shtc3));
    m_readings.emplace_back(new PacketHumidityReading(idx(), s_shtc3));
    m_readings.emplace_back(new PacketMoistureReading(idx(), s_moisture, s_moisture_filter));
    m_readings.emplace_back(new satellite::PacketVoltageReading(idx(), s_five_v_sensor));
    m_readings.emplace_back(new satellite::PacketVoltageReading(idx(), s_battery_sensor));
    m_readings.emplace_back(new satellite::PacketVoltageReading(idx(), s_solar_sensor));
    m_readings.emplace_back(
        new satellite::PacketIntReading(idx(), "soil ADC counts", s_moisture.countsVar()));
    m_readings.emplace_back(new satellite::PacketIntReading(idx(), "status", s_status_var));
#if defined(HAVE_STANDBY_INPUT)
    m_readings.emplace_back(new satellite::PacketIntReading(idx(), "charge", s_var_charge));
    m_readings.emplace_back(new satellite::PacketIntReading(idx(), "standby", s_var_standby));
#else
    m_readings.emplace_back(new satellite::PacketIntReading(idx(), "wake time", s_wake_secs));
    m_readings.emplace_back(
        new satellite::PacketIntReading(idx(), "last wake time", s_last_wake_secs));
#endif
  }

  void update() {
    SETSTR(m_mutable_device->name, s_app.board_cname());
    const int64_t now_usecs = total_usecs();
    const int64_t now_secs = now_usecs / kUsecInSec;
    const int64_t secs_since_info_sent = now_secs - m_rtc->secs_device_sent;
    s_app.log().debugf("now_secs:%llu secs_since_info_sent:%llu", now_secs, secs_since_info_sent);

    const bool need_to_send_info = s_boot || (secs_since_info_sent >= 3600);
    if (need_to_send_info) {
      m_rtc->secs_device_sent = now_secs;
      m_rtc->sensor_descriptions_sent = 0;
    }
    s_status_var = s_rtc.code;
    s_board_id_var = s_board_id;
#if defined(HAVE_STANDBY_INPUT)
    s_var_charge = s_din_chrg.read() ? 1 : 0;
    s_var_standby = s_din_stby.read() ? 1 : 0;
#endif

    if (s_boot) {
      // At boot, for each sensor send one packet describing the sensor.
      const int max_packet = s_lora.usa_max_payload();
      constexpr int packet_overhead = pkt::kHeaderSize + pkt::kMsgHeaderSize + sizeof(uint32_t);
      const int max_payload = max_packet - packet_overhead;
      if (max_payload < 8) {
        s_app.log().logf("Max packet %d - overhead %d is too small", max_packet, packet_overhead);
        return;
      }
      send_desc(max_payload);
    } else {
      send_all_readings();
    }
  }

 protected:
  void send_packet(og3_Packet& packet) override {
    uint8_t msg_buffer[kLoraPacketSize];
    pb_ostream_t ostream = pb_ostream_from_buffer(msg_buffer, sizeof(msg_buffer));
    if (!pb_encode(&ostream, &og3_Packet_msg, &packet)) {
      s_app.log().log("Failed to pb_encode packet.");
      return;
    }

    uint8_t pkt_buffer[og3_Packet_size + pkt::kHeaderSize + pkt::kMsgHeaderSize];
    pkt::PacketWriter writer(pkt_buffer, sizeof(pkt_buffer), m_rtc->seq_id++);
    if (!writer.add_message(kDevicePktType, msg_buffer, ostream.bytes_written)) {
      s_app.log().log("Failed to add device msg to packet.");
      return;
    }
    if (!writer.add_crc()) {
      s_app.log().log("Failed to add CRC to packet.");
      return;
    }

    // s_led.on();
    s_lora.send_packet(pkt_buffer, writer.packet_size());
    s_app.log().debugf("Sent LoRa packet (seq_id:%u, %zu bytes).", m_rtc->seq_id - 1,
                       ostream.bytes_written);
  }

  // Non-const pointer so we can update the name.
  og3_Device* m_mutable_device;
};

og3_Device* s_device() {
  static og3_Device ret;

  ret.id = s_board_id;  // may not be set yet
  ret.manufacturer = kCleeOrg;
  SETSTR(ret.name, s_app.board_cname());
  SETSTR(ret.device_type, kModel);
  ret.hardware_version.major = HARDWARE_VERSION_MAJOR;
  ret.hardware_version.minor = HARDWARE_VERSION_MINOR;
  ret.software_version.major = VERSION_MAJOR;
  ret.software_version.minor = VERSION_MINOR;
  ret.software_version.patch = VERSION_PATCH;
  ret.timeout_secs = s_sleep_min.value() * 60 * 3 + 10;
  return &ret;
}

LoraPacketSender s_packet_sender(s_device(), &s_app, &s_rtc.packet_sender);

std::unique_ptr<PeriodicTaskScheduler> s_hourly_lora;

bool print_wakeup_reason() {
  const esp_sleep_wakeup_cause_t wakeup_reason = esp_sleep_get_wakeup_cause();

  switch (wakeup_reason) {
    case ESP_SLEEP_WAKEUP_EXT0:
      s_app.log().log("Wakeup caused by external signal using RTC_IO");
      break;
    case ESP_SLEEP_WAKEUP_EXT1:
      s_app.log().log("Wakeup caused by external signal using RTC_CNTL");
      break;
    case ESP_SLEEP_WAKEUP_TIMER:
      s_app.log().log("Wakeup caused by timer");
      break;
    case ESP_SLEEP_WAKEUP_TOUCHPAD:
      s_app.log().log("Wakeup caused by touchpad");
      break;
    case ESP_SLEEP_WAKEUP_ULP:
      s_app.log().log("Wakeup caused by ULP program");
      break;
    default:
      s_app.log().logf("Wakeup was not caused by deep sleep: %d\n", wakeup_reason);
      return true;
  }
  return false;
}

WebButton s_button_wifi_config = s_app.createWifiConfigButton();
WebButton s_button_mqtt_config = s_app.createMqttConfigButton();
WebButton s_button_app_status = s_app.createAppStatusButton();
WebButton s_button_restart = s_app.createRestartButton();

NetHandlerStatus handleWebRoot(NetRequest* request, NetResponse* response) {
  const int64_t now_usecs = total_usecs();

  // Read the sensors.
  s_shtc3.read();
  s_moisture_filter.addSample(now_usecs * 1e-6, s_moisture.read());
  s_five_v_sensor.read();
  s_battery_sensor.read();
  s_solar_sensor.read();
#if defined(HAVE_STANDBY_INPUT)
  s_var_charge = s_din_chrg.read() ? 1 : 0;
  s_var_standby = s_din_stby.read() ? 1 : 0;
#endif

  // Write the page.
  s_html.clear();
  html::writeTableInto(&s_html, s_vg);
  html::writeTableInto(&s_html, s_app.wifi_manager().variables());
  html::writeTableInto(&s_html, s_app.mqtt_manager().variables());

  s_moisture.add_html_button(&s_html);
  s_five_v_sensor.add_html_button(&s_html);
  s_battery_sensor.add_html_button(&s_html);
  s_solar_sensor.add_html_button(&s_html);

  s_html += HTML_BUTTON("/lora", "LoRa");
  s_button_wifi_config.add_button(&s_html);
  s_button_mqtt_config.add_button(&s_html);
  s_button_app_status.add_button(&s_html);
  s_button_restart.add_button(&s_html);
  sendWrappedHTML(request, response, s_app.board_cname(), kSoftware, s_html.c_str());
  NET_REPLY(request, ESP_OK);
}

NetHandlerStatus handleLoraConfig(NetRequest* request, NetResponse* response) {
  read(*request, s_lora_vg);
  s_html.clear();
  html::writeFormTableInto(&s_html, s_lora_vg);
  s_html += HTML_BUTTON("/", "Back");
  sendWrappedHTML(request, response, s_app.board_cname(), kSoftware, s_html.c_str());
  s_app.config().write_config(s_lora_vg);
  NET_REPLY(request, ESP_OK);
}

void start_sleep() {
  s_app.log().debug("Sleeping");
  s_rtc.code &= ~Status::kDebugMode;

  // Save filter state to memory that is preserved when sleeping.
  if (!s_moisture_filter.saveState(s_rtc.filter_state)) {
    s_rtc.code |= Status::kFilterSaveFailure;
  }

  og3::s_lora.sleep();

  // Set a timer which will wakeup the board, then put the board into deep sleep.
  s_rtc.last_wake_secs = s_rtc.expected_wake_secs;
  s_rtc.expected_wake_secs = s_rtc.last_wake_secs + kSecInMin * s_sleep_min.value();

  esp_sleep_enable_timer_wakeup((kSecInMin * s_sleep_min.value()) * kUsecInSec -
                                esp_timer_get_time());
  esp_deep_sleep_start();
}

static String s_body;

NetHandlerStatus apiGetWifi(NetRequest* request, NetResponse* response) {
  JsonDocument jsondoc;
  JsonObject json = jsondoc.to<JsonObject>();
  s_app.wifi_manager().variables().toJson(json, VariableBase::kConfig);
  s_body.clear();
  serializeJson(jsondoc, s_body);
  response->send(200, "application/json", s_body.c_str());
  NET_REPLY(request, ESP_OK);
}

NetHandlerStatus putWifiConfig(NetRequest* request, NetResponse* response, JsonVariant& jsonIn) {
  if (!jsonIn.is<JsonObject>()) {
    response->send(500, "text/plain", "not a json object");
    NET_REPLY(request, ESP_FAIL);
  }
  JsonObject obj = jsonIn.as<JsonObject>();
  s_app.wifi_manager().variables().updateFromJson(obj);
  s_app.config().write_config(s_app.wifi_manager().variables());
  response->send(200, "text/plain", "ok");
  NET_REPLY(request, ESP_OK);
}

NetHandlerStatus apiGetMqtt(NetRequest* request, NetResponse* response) {
  JsonDocument jsondoc;
  JsonObject json = jsondoc.to<JsonObject>();
  s_app.mqtt_manager().variables().toJson(json, VariableBase::kConfig);
  s_body.clear();
  serializeJson(jsondoc, s_body);
  response->send(200, "application/json", s_body.c_str());
  NET_REPLY(request, ESP_OK);
}
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
void loop() {
  og3::s_app.loop();

  // Check the debug-mode toggle button again, so we can switch away from debug mode
  //  while the board is running.
  og3::s_is_debug_mode = digitalRead(og3::kDebugSwitchPin);

  if (og3::s_is_debug_mode) {
    return;  // In debug mode, all the work happens in og3::s_app.loop().
  }

  // Here, we are in "normal mode", where we normally take readings, send them via LoRa,
  //  then go into deep sleep for a while to preserve power.

  // Wait up to 10 seconds for LoRa to start-up at boot.
  // After that, if LoRa isn't running, just sleep.
  if (!og3::s_lora.is_ok()) {
    if (millis() < og3::kMsecInSec * 10) {
      return;
    }
    og3::start_sleep();
  }

  // Here, we are in "normal mode" and the LoRa radio is running.

  // Just once, read the sensors, and send a LoRa packet.
  static bool s_sent = false;
  if (!s_sent) {
    og3::s_packet_sender.update();
    s_sent = true;
  }

  // Here, we have sent a packet and may send further ones before sleeping.
  // Wait for is_sending() to be unset, meaning that all packets have been sent,
  //  then wait for 1 second and then go to sleep.
  if (og3::s_packet_sender.is_sending()) {
    return;
  }

  // Here, all packets have been sent.
  // Schedule a sleep in 1 second if not yet started.
  static bool s_sleep_started = false;
  if (!s_sleep_started) {
    s_sleep_started = true;
    og3::s_app.tasks().runIn(og3::kMsecInSec, og3::start_sleep);
    og3::s_led.blink(1);
  }
}

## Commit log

2025-06-15 WIP -- KiCAD, packet format, device protos
    [Garden133.kicad_pcb, Garden133.kicad_sch, esp32_no_serial.kicad_sch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]
2025-06-15 Updated device protobuf, got LoRa working.
2025-06-15 Read temp/humidity and moisture sensors, and send via LoRa+MQTT
2025-06-15 Board version 5
    [Garden133.kicad_pcb, Garden133.kicad_sch, esp32_no_serial.kicad_sch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]
2025-06-15 Update for board v6
    - Added OpenSCAD models for Solar panel mount, tray for board+battery
    - ADC Adjustment because using 220k resistors, not 200k.
    - Licenses updated
    - Remove support for v4 boards, update ADC slopes
    - Board v6.0 (ordered)
    - Support publishing more data via LoRa.
    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
    [Garden133.kicad_pcb, Garden133.kicad_sch, Garden133_test.scad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]
2025-06-15 Send full device info every hour, brief info otherwise.
2025-06-15 Soil moisture sensor potting frame -- initial version
    [soilpot.scad, soilpot.stl]
2025-06-15 support blinking the LED
2025-06-15 solar ADC divide-down is now 2
2025-06-15 Allow turning-off debug mode.
    Note that this does not power-down WiFi.
2025-06-15 Soil moisture sensor potting frame -- version 2
    [soilpot.scad, soilpot.stl]
2025-06-15 Update PCB
    - Button controls power to 3.3V LDO
    - DIO readings for STDBY and CHRG
    [Garden133.kicad_pcb, Garden133.kicad_sch, esp32_no_serial.kicad_sch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]
2025-06-15 Soil-sensor potting case update
    [soilpot.scad, soilpot.stl]
2025-06-15 ADC counts change from number -> unspecified
2025-06-15 First draft of new moisture sensor cap
    [box_bottom.scad, box_top.scad, cap2.scad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]
2025-06-15 Version 2 of moisture sensor cap
    - More space for connector
    - Tighter hole for sensor
    - Clamp top & bottom around the wire.
    [cap2.scad]
2025-06-15 Version 3 of moisture sensor cap
    - Thicker minimum wall thickness.
    - More space at top of connector for wire into JST
    - Lip at side of box to lock it into place
    - Screw holes near top (away from point) of sensor)
    [cap2.scad]
2025-06-15 Version 4 of moisture sensor cap
    - Shorter
    - Thinner slot for sensor board.
    - Shrink hole for connector
    [cap2.scad, moisture_sensor.scad]
2025-06-15 Version 4a of moisture sensor cap
    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
    [cap2.scad]
2025-06-15 og3->0.3.16, use crc32 for LoRa packets, ignore moisture when <3.3V
2025-06-15 Update: version -> 0.4.0
    - Fix boot-count, seq_id
    - Had initializers for some rtc values such as boot count, so these were being
    reset after sleep.
    - Fix logic for sending sensor-reading descriptions every hour.
    - Board stays alive a short time after sending messages to blink led.
    [main.cpp]
2025-06-15 Fix led-blinking
2025-06-15 Attempt to avoid brown-out during desc-send
    Adjustments to deal with the fact that boards seemed to be browning-out when
    descriptions packets were being sent every second. Maybe the LDO+capacitors
    cannot keep up with this level of power usage?
    - Slow desc-sends to 1 every 5 seconds.
    - Make sure serial logging is turned off after USB code update.
    Maybe the board needs a bulk capacitor for 3.3V?
    [main.cpp]
2025-06-15 Solar panel holder for smaller panel
    [solar_panel_mount.scad]
2025-06-15 Fixes to avoid brown-outs
    - Only send one packet between sleeping after initial sensor descriptions are sent.
    - Each hour, for the first N-packets, send information about the N-th sensor.
    In the first packet send the device info.
    - The board reliably browns-out after sending 2 LoRa packets and never recovers, when
    battery-powered at least (and maybe also when connected to the moisture sensor).
    - Add more bits to the boot-count in rtc memory. It was going to roll over after 45
    days, and integer-overflow in an expression might be why sensor descriptions were not
    resent after the second hour of operation.
    - Send wake-up time and last time sensor information was sent i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
    [main.cpp]
2025-06-15 OpenSCAD: waterproof enclosure, stls for soil moisture cap
    [box_bottom.stl, box_top.stl, garden133_case_top.stl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]
2025-06-15 Garden133 Board v6.2 (ordered from PCBWay)
    [Garden133.kicad_pcb, Garden133.kicad_sch, solar.kicad_sch]
2025-06-15 boards update
2025-06-19 update for board v6.2 (#1)
    - Fix 20k resistor
    - Board v6.2 update: standby/charge detection
    -Maybe also fix hourly update?
    [solar.kicad_sch]
2025-06-22 Updates (#2)
    * KiCAD model: remove duplicate battery connection
    * Fix for standby/charge DIn detection
    [solar.kicad_sch]
2025-07-07 KiCAD v62 fixes, README update, code update (#3)
    * Code: Fix for standby/charge DIn detection
    * Update README
    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
2025-07-19 version -> 0.6.0 (#4)
    - Used updated og3x-satellite with updated protocol
    - Set board name as device name in device protobuf
    - Set model name as device_type (new field) in device protobuf
2025-10-19 soil moisture cap update (#5)
    - Updated soil moisture cap design.
    - Depdencency cleanups to get the build to work again.
    - Code-comment edits
    [box_bottom.stl, box_top.stl, cap2.scad]
2026-01-28 Board update, README update (#6)
    - Board updae
    - README update, assisted by Gemini.
    - Bump dependencies.
    [Garden133.kicad_pcb]
2026-04-03 Version 1.0.0 (#7)
    ## [1.0.0] - 2026-03-29
    ### Added
    - New responsive Svelte web interface for status monitoring and configuration (Debug Mode).
    - JSON API for full device control and status reporting.
    - Standardized `camelCase` naming for all API keys and internal variables.
    - Dedicated Moisture Calibration page with live ADC count monitoring.
    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
    [Garden133_test.scad, board.scad, box.scad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]
